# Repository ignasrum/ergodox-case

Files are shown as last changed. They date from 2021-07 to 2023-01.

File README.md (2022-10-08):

# Ergodox Case (1u - 80 key)

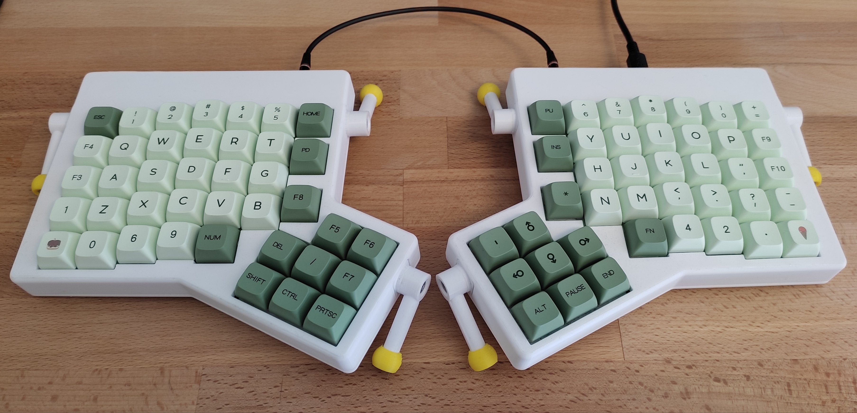
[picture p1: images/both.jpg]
both


### Parts to assemble both sides:

| Count | Part | Notes |
|:-----:|:---:|:---:|
| 2 | bottom | 1 with usb, 1 without usb |
| 2 | top | 1 with usb, 1 without usb |
| 2 | plates | |
| 6 | legs | |
| 6 | feet | |
| 18 | M3 inserts | |
| 6 | M3 nuts | |
| 12 | 10mm M3 screws | for attaching bottom to top  |
| 6 | 16mm M3 screws | for attaching legs to bottom |
| 6 | 4mm M3 screws | for attaching feet to legs |

### Notes

* The case only supports 1u outer row. 
* Currently, the plate only support 1u thumb cluster keys, but the plate may be easily adapted to support 2u keys.
* Only one stl is provided for each part. Mirror the parts depending on your setup.
* Plates with and without supports are provided. The version without supports is mainly meant for cutting out from acrylic etc.
* Use as small and narrow M3 inserts as possible, some of the wider ones may not fit.
* Use countersunk screws.
* Feet should be printed in TPU or any other soft filament (for better grip).
* The case supports PCB thickness of about 1.55-1.65 mm.
* This case is not made to print fast or save filament, it's thick, robust, and strong.

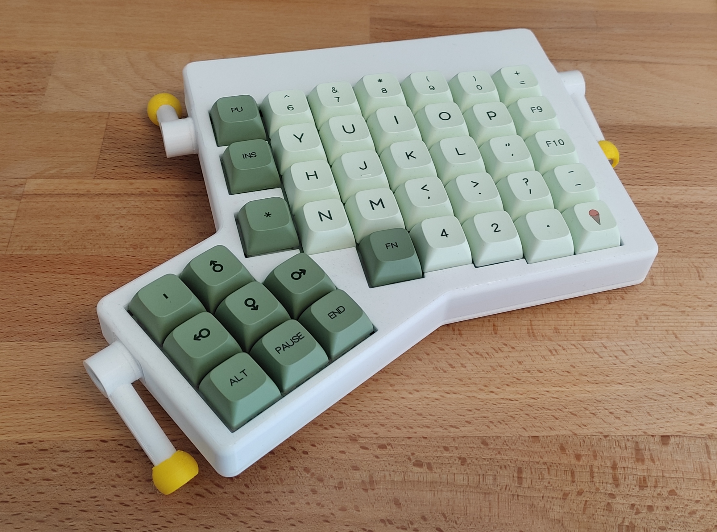
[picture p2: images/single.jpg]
single


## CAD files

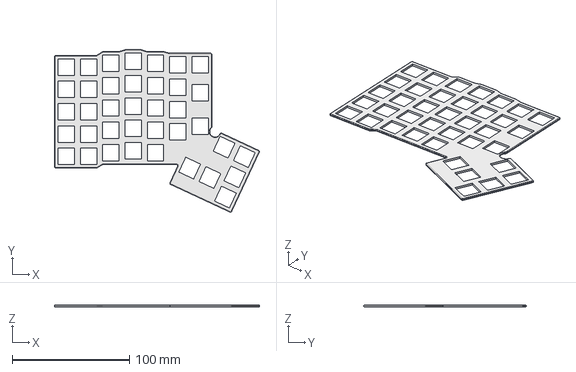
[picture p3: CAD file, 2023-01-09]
2u-thumb-plate-no-supports/2u-thumb-plate-no-supports.step
174.9 x 138.7 x 1.50 mm

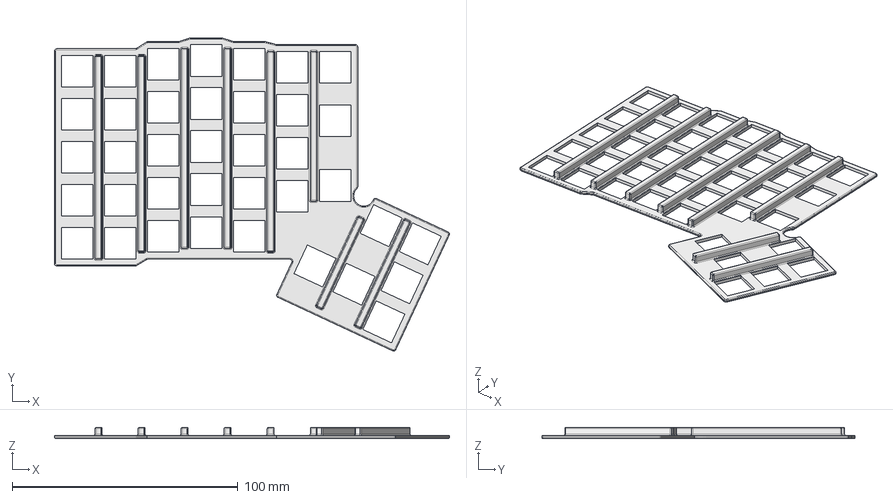
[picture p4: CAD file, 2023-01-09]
2u-thumb-plate-with-supports/2u-thumb-plate-with-supports.step
174.9 x 138.7 x 5.00 mm

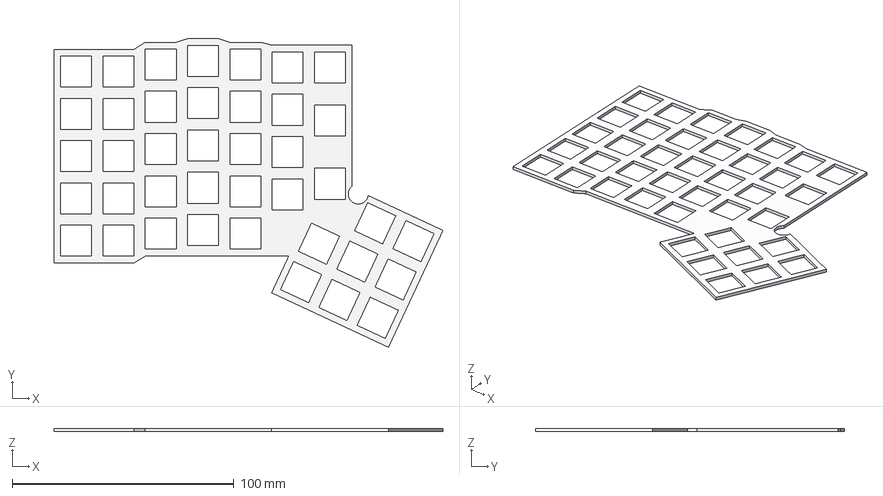
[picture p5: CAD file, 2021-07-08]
all-1u-plate-no-supports/all-1u-plate-no-supports.step
175.2 x 139.0 x 1.50 mm

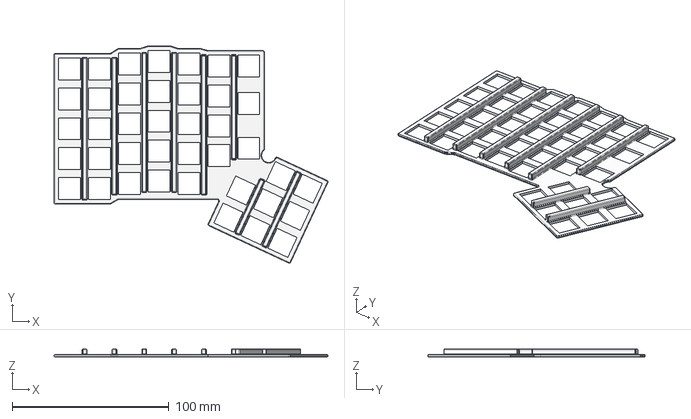
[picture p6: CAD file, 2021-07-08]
all-1u-plate-with-supports/all-1u-plate-with-supports.step
174.9 x 138.7 x 5.00 mm

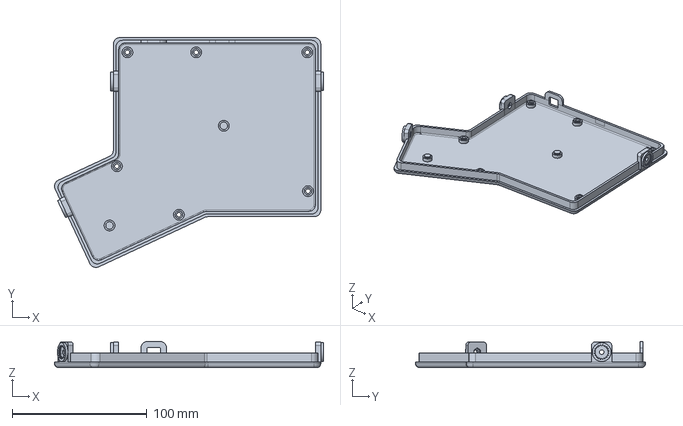
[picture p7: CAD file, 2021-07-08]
bottom-no-usb/bottom-no-usb.iges
199.6 x 170.7 x 19.5 mm

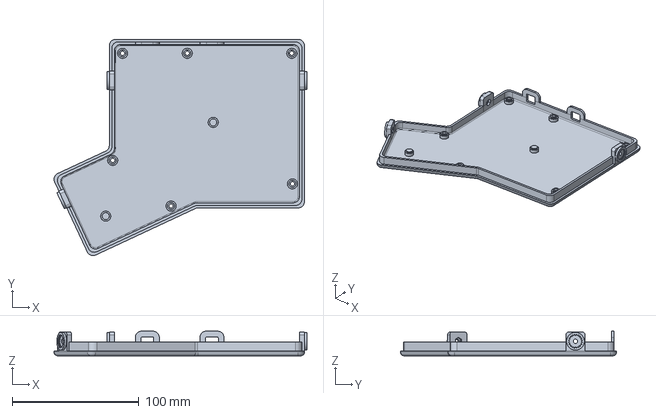
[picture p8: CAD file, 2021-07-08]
bottom-with-usb/bottom-with-usb.iges
199.6 x 170.7 x 19.5 mm

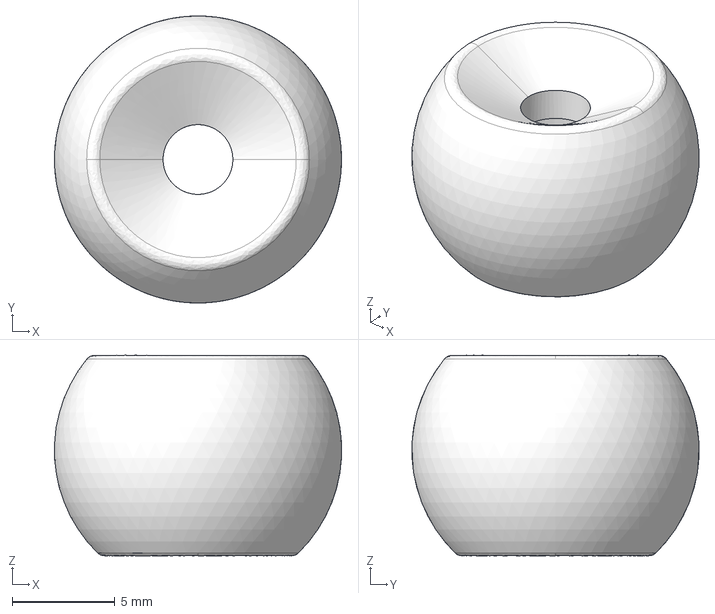
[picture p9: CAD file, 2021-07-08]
foot/foot.step
14.0 x 14.0 x 9.77 mm

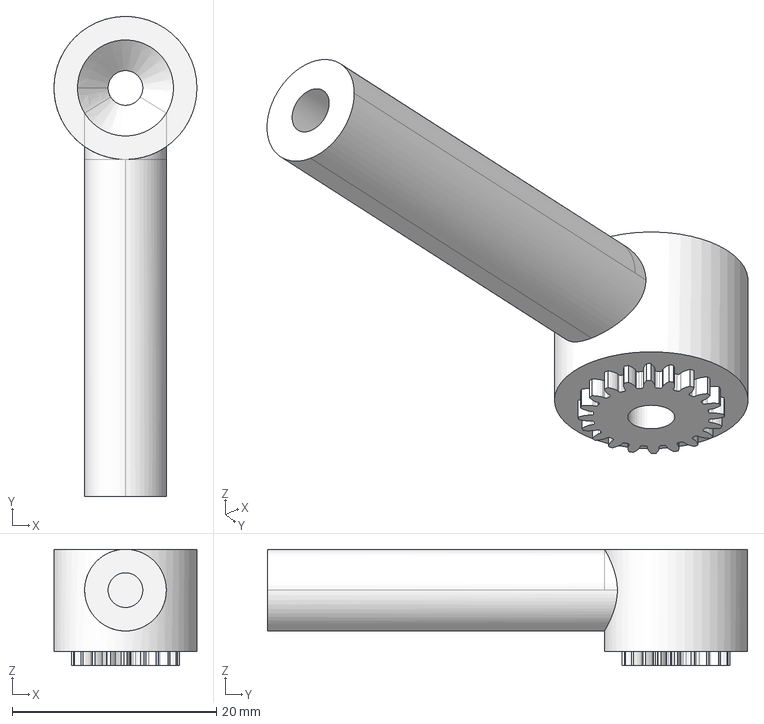
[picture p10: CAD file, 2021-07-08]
leg/leg.step
14.0 x 47.0 x 11.4 mm

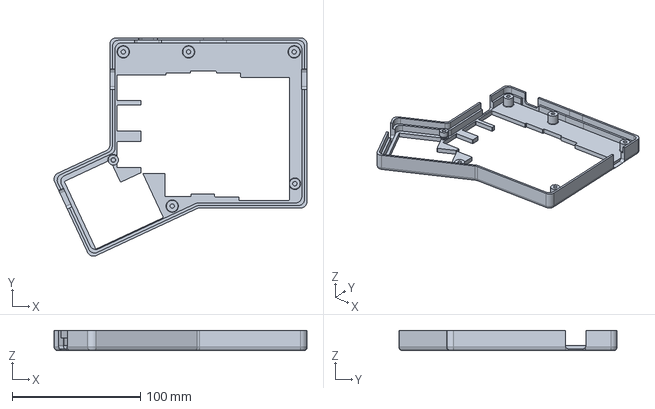
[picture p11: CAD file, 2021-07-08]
top-no-usb/top-no-usb.iges
197.6 x 170.7 x 16.0 mm

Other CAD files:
top-with-usb/top-with-usb.iges
2u-thumb-plate-no-supports/2u-thumb-plate-no-supports.stl
all-1u-plate-no-supports/all-1u-plate-no-supports.stl
bottom-no-usb/bottom-no-usb.stl
bottom-with-usb/bottom-with-usb.stl
foot/foot.stl
leg/leg.stl
top-no-usb/top-no-usb.stl
top-with-usb/top-with-usb.stl

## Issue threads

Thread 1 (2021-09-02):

Settings and Plate

Lachlancg, 2021-09-02:
Hi, this project is really cool! I'm attempting to print on my ender3 and wondered what settings you used to slice the files?
I also wondered which plate you would recomend printing? the one with supports or no supports?

ignasrum, 2021-09-02:
Hi!

I can't really help you with slicer settings because it depends on the slicer itself, the printer, the filament etc. My ender 3 pro is not stock as it has an skr 1.3 motherboard, direct extrusion and so on, so my slicer settings will most likely not apply to your printer.

Regarding the plate, I have built two keyboards, one which has a plate with supports and another without supports. A 1.5 mm plate printed in PETG just isn't very solid and the switches may not seat properly in the plate some places because it may be bent a bit etc. I would recommend printing a plate with supports because it feels more solid once assembled.

Lachlancg, 2021-09-02:
Sorry I meant to add that I'm also using an ender 3 pro but it seems mines not quite as upgraded as yours.

Thanks for the heads up on the build plate with supports. I'm actually gonna try and use PLA and see how it holds up. Maybe in the future I'll print again in PETG.

ignasrum, 2021-09-02:
If you had problems printing with PETG, just print at a high temperature (I'm printing at 240 celsius), and print slowly (I'm printing at 40mm/s). You may also try enabling retraction, but the specific settings depend on your setup (bowden vs direct extruder).

Lachlancg, 2021-09-02:
I've actually only been printing a few weeks so I haven't tried PETG yet, I've currently got a BMG clone extruder and plan to upgrade to direct drive with it at some point. I'm trying to do upgrades one at a time so that I can troubleshoot any problems easier. Before I print PETG I was planning on upgrading the hot end so that I don't get the PTFE tube melting problems.

Have you found the printed feet offer good traction for the board, or does it move around on the desk easily?

Thanks for all your advice so far, I really appreciate how friendly and willing to help the 3d printing community is.

ignasrum, 2021-09-02:
The TPU I used is not super soft so it does move a bit, but it's not annoying. If you want really good traction, you would need to use 85A-75A TPU or something similar.

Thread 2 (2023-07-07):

Plate & Handwireing

nomeaning25, 2023-07-07:
The plates are probably not meant to be used in handwired keyboard?

ignasrum, 2023-07-09:
Yeah, the plates were not made for handwired keyboards.

nomeaning25, 2023-07-13:
I remixed the one without support an added some cylinders for screws. It's not perfect but it will do. Just need to drill the holes in the bottom parts. Will have some issues to align the keyboard but I think I will manage :)

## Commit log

2022-10-08 modified folder structure
    [bottom-no-usb.iges, bottom-no-usb.stl, bottom-with-usb.iges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]
2023-01-09 added 2u thumb cluster support (plates)
    [2u-thumb-plate-no-supports.step, 2u-thumb-plate-no-supports.stl, 2u-thumb-plate-with-supports.step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]
